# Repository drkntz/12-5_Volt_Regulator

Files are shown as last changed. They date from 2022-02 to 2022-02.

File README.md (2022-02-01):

# 12-5_Volt_Regulator
12 to 5 volt DC regulator @ 3A

#Schematic rev 2
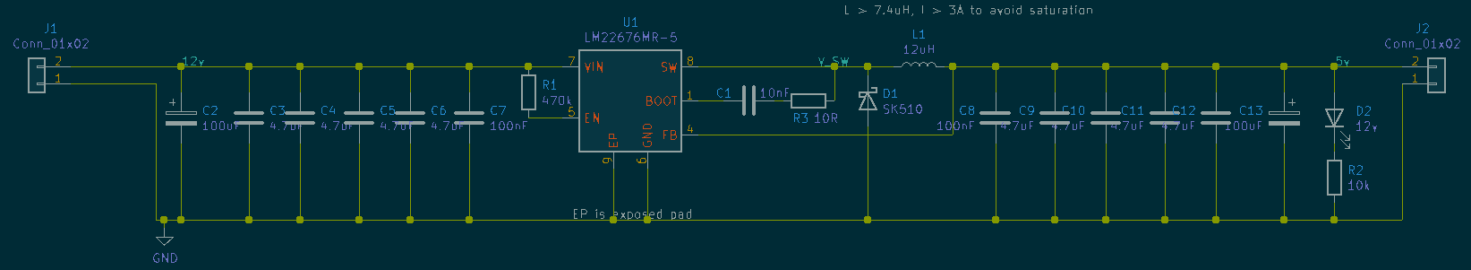
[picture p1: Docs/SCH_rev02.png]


#Layout rev 2
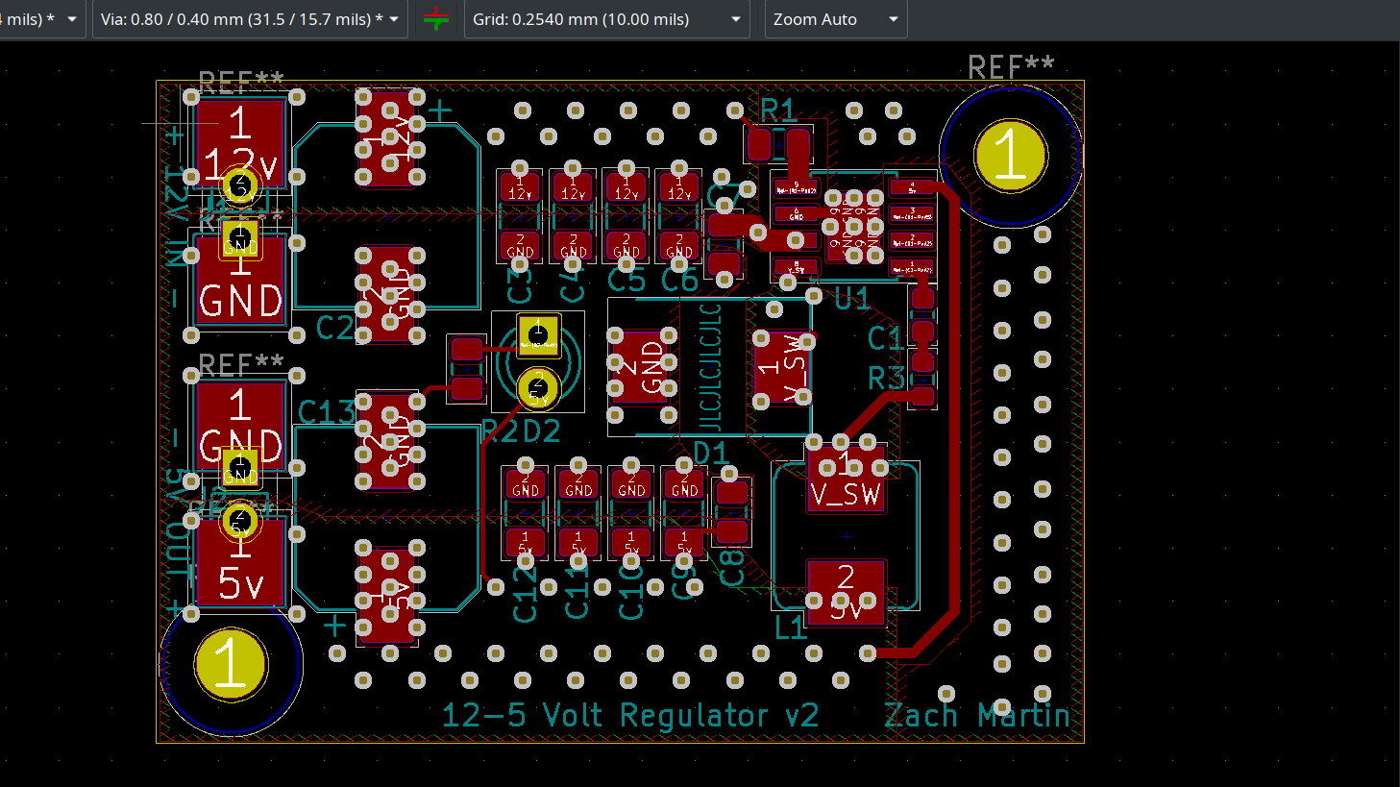
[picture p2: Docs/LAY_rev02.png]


#3-D PCB Image rev 2
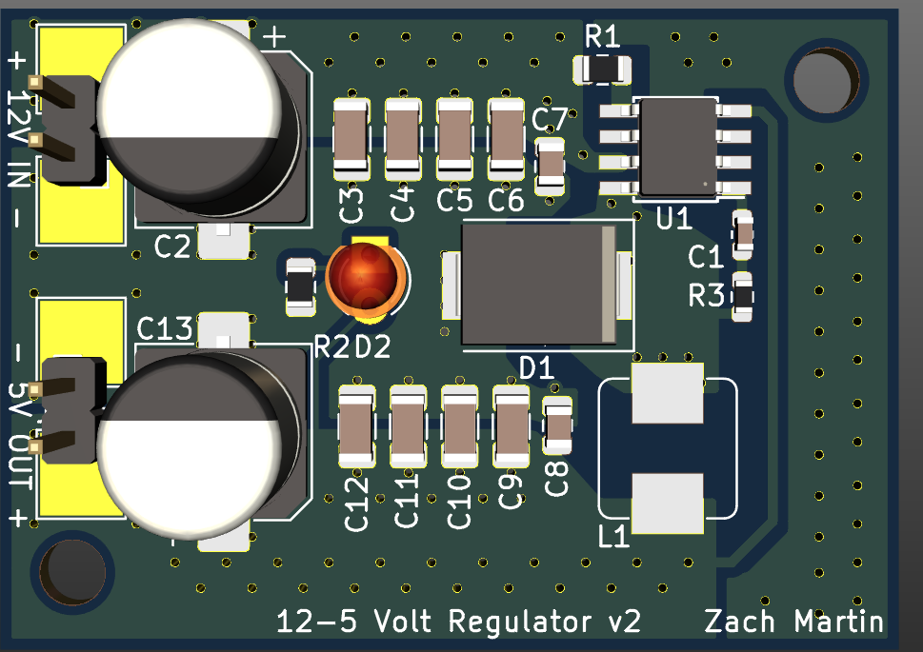
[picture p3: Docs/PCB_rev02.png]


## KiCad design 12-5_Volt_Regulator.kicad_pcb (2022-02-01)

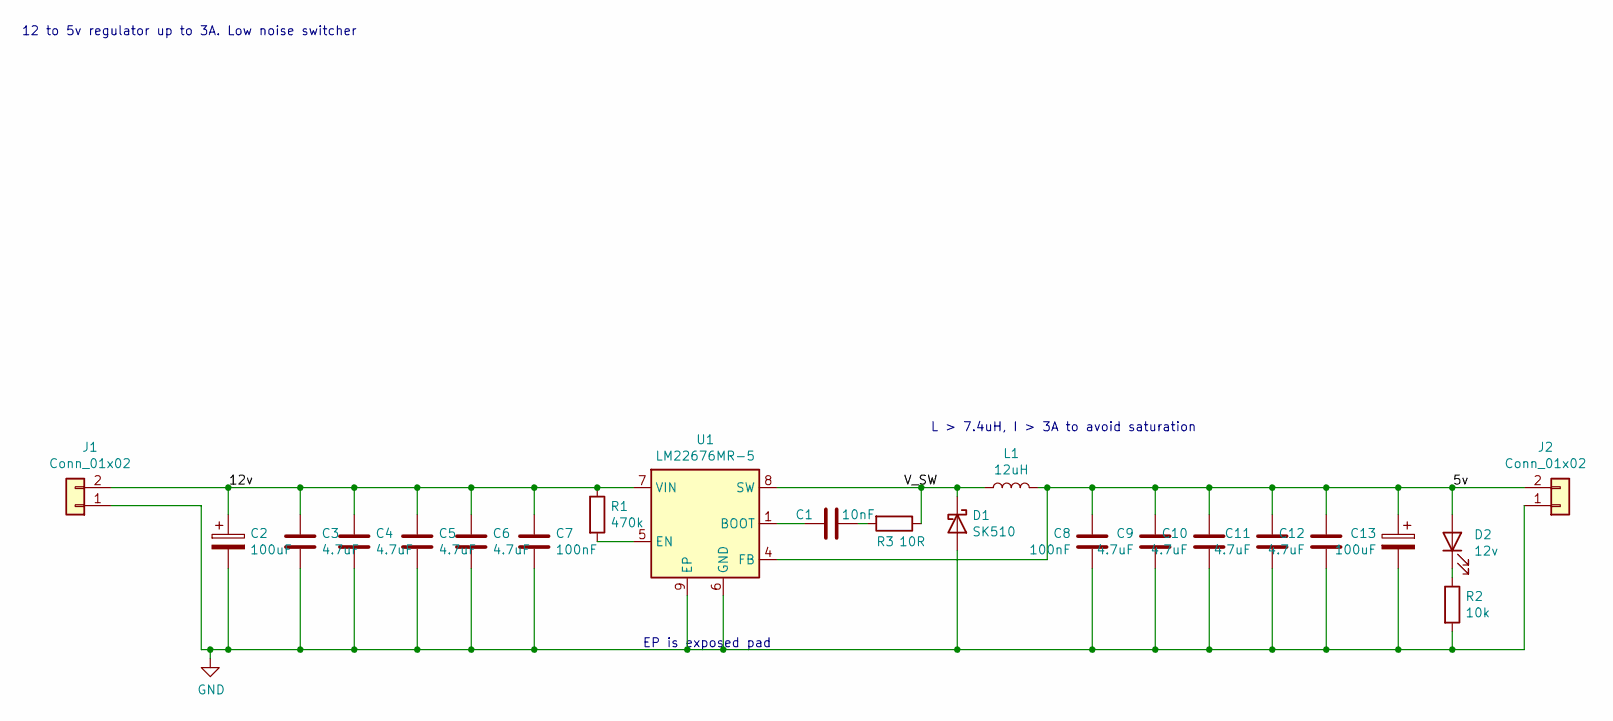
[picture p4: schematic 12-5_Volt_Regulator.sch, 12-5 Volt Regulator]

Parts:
C1: 10nF; C_0603_1608Metric
C2, C13: 100uF; CP_Elec_8x10.5
C3, C4, C5, C6, C9, C10, C11, C12: 4.7uF; C_1206_3216Metric
C7, C8: 100nF; C_0805_2012Metric
D1: SK510; D_SMC
D2: 12v; LED_D3.0mm
J1, J2: Conn_01x02; PinHeader_1x02_P2.54mm_Vertical
L1: 12uH; L_Bourns_SRP7028A_7.3x6.6mm
R1: 470k; R_0805_2012Metric
R2: 10k; R_0805_2012Metric
R3: 10R; R_0603_1608Metric
U1: LM22676MR-5; TI_SO-PowerPAD-8

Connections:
/5v: C8.1, C9.1, C10.1, C11.1, C12.1, C13.1, D2.2 (A), J2.2, L1.2, U1.4 (FB)
/12v: C2.1, C3.1, C4.1, C5.1, C6.1, C7.1, J1.2, R1.1, U1.7 (VIN)
/V_SW: D1.1 (K), L1.1, R3.1, U1.8 (SW)
GND: C2.2, C3.2, C4.2, C5.2, C6.2, C7.2, C8.2, C9.2, C10.2, C11.2, C12.2, C13.2, D1.2 (A), J1.1, J2.1, R2.2, U1.6 (GND), U1.9 (EP)
unnamed: C1.1, R3.2
unnamed: C1.2, U1.1 (BOOT)
unnamed: D2.1 (K), R2.1
unnamed: R1.2, U1.5 (EN)

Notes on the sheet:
12 to 5v regulator up to 3A. Low noise switcher
EP is exposed pad
L > 7.4uH, I > 3A to avoid saturation

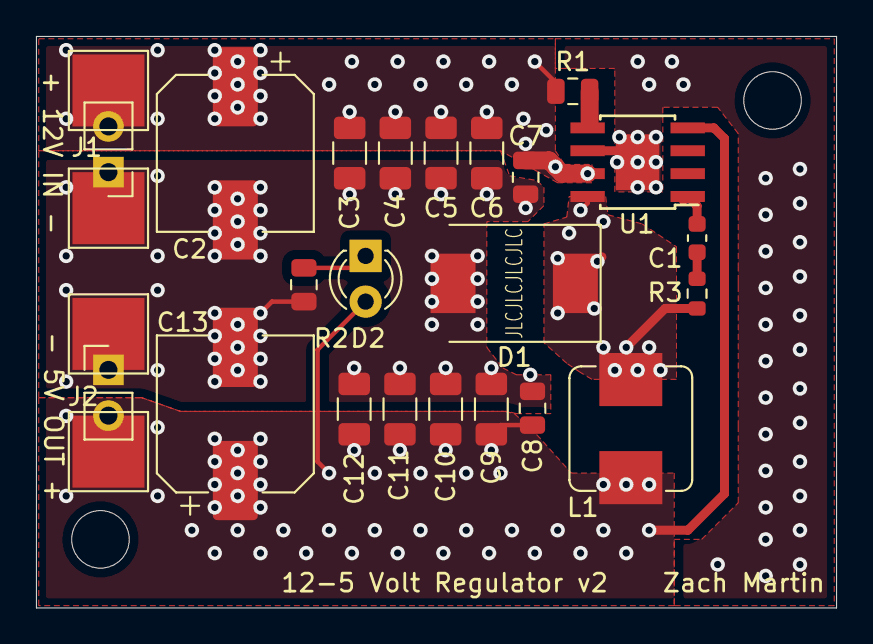
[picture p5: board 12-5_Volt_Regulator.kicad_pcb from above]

Board: 2 copper layers, 44.4 x 31.8 mm, 22 parts (0 on the bottom side), 8 nets.

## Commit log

2021-07-20 Initial commit: TI simple switcher, v0 board layout
    [12-5_Volt_Regulator.kicad_pcb, 12-5_Volt_Regulator.sch]
2021-07-20 Added wire pads, removed vias & fills as I switched grid spacing
    [12-5_Volt_Regulator.kicad_pcb, 12-5_Volt_Regulator.sch]
2021-07-20 Re-routed zone boundaries
    [12-5_Volt_Regulator.kicad_pcb]
2021-07-20 Updated vias, traces, fills, JLCPCB part # location. Ready for ordering
    [12-5_Volt_Regulator.kicad_pcb]
2022-02-01 Rev 2. Fixed feedback loop, added R3 for EMI suppression
    [12-5_Volt_Regulator-B_Cu.gbl, 12-5_Volt_Regulator-B_Mask.gbs, 12-5_Volt_Regulator-B_Paste.gbp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]
